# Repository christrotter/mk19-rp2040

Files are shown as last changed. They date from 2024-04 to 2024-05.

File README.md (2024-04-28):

# mk19-rp2040
Attempting to reduce soldering to a minimum - only need to solder the JST-XH headers.  This is the mainboard for the [ArcBoard-mk19](https://github.com/christrotter/qmk_firmware/tree/arcboard-series/keyboards/handwired/arcboard_mk19).

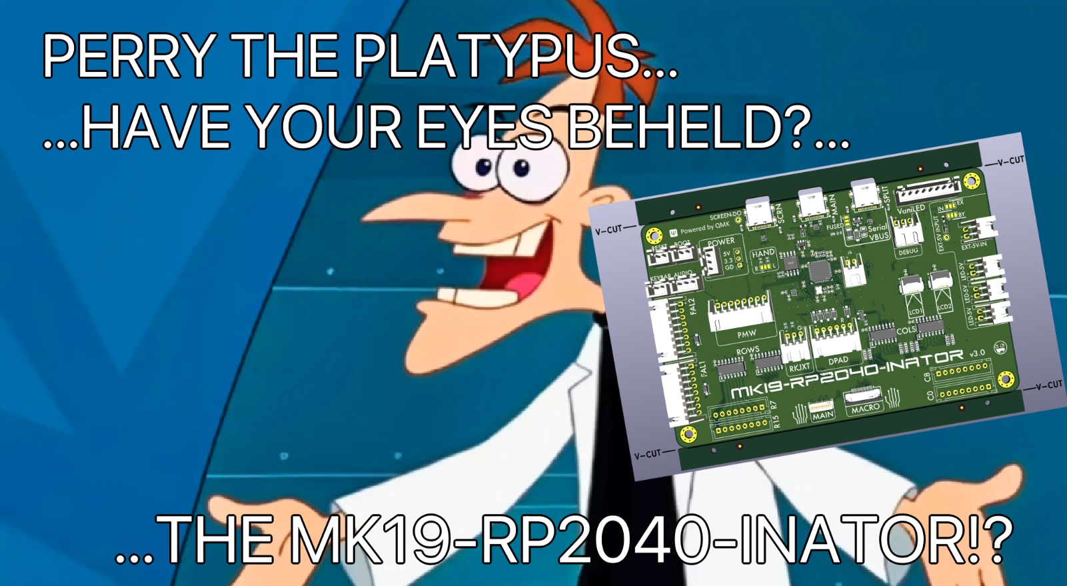
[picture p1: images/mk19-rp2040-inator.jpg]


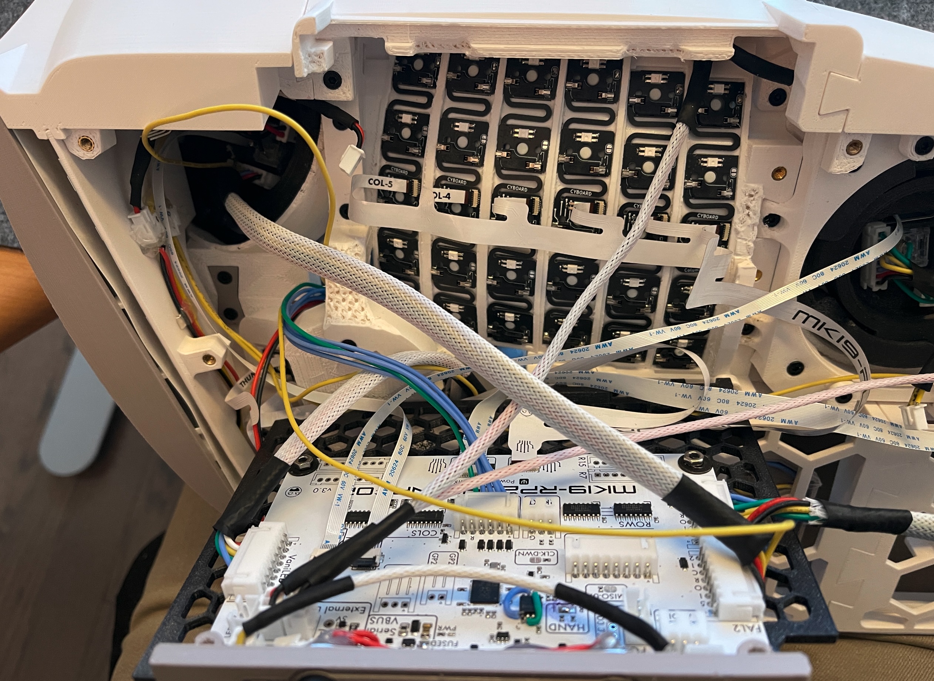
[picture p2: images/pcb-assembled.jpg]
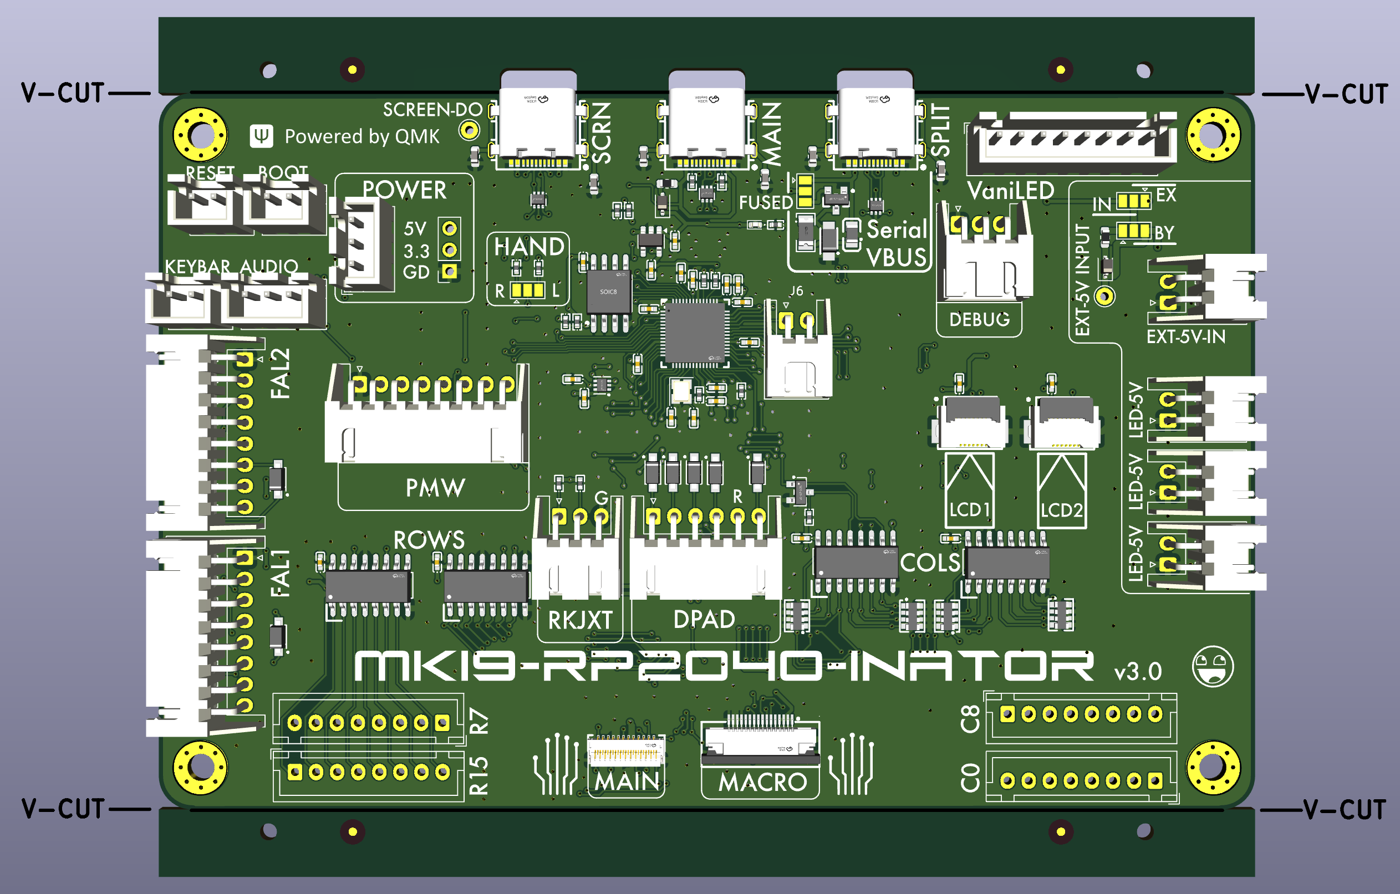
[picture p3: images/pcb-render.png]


# Features
- On-board RP2040 w. 16MB flash (_based on splinktegrated and reference design_)
- USB-C connectivity for main, split, and screen indicators
- Boot and reset button headers
- Serial vbus power protection (_ESD, polyfuse, diode, etc_)
- External 5v input for LED power (_polyfuse, diode_)
- SPI shift registers to handle rows and cols - up to 256 keys per half - with row/col pin breakouts
- SPI LCD outputs via 0.5mm FPC connectors
- 0.3mm FPC connector for [Cyboard](https://www.cyboard.digital/product-page/dactyl-flex-pcbs) connectivity (or via [this](https://github.com/christrotter/mk19-flex-pcb))
- 0.5mm [macropad](https://github.com/christrotter/macropad-pcb) connector
- Dpad input with diodes (_[RKJXT w. encoder](https://github.com/christrotter/rkjxt-mini-breakout), [5-way](https://github.com/christrotter/5way-pcb), or [4-switch dpad](https://github.com/christrotter/microswitch-dpad)_)
- PMW33XX connector
- 2x [Ultrafalcon](https://github.com/christrotter/ultrafalcon) connectors
- VaniLED connector (_GND,5V,4 gpio; for controlling a secondary RP2040 that handles extra LEDs_)
- Audio, debug, spare pin, power breakouts
- Split-handedness pin solder jumper
- Optional SPI clock pull-down and SPI MISO pull-up resistors
- Test points

# Functional notes
- The LED DI/DO chain flows from main keys (_Cyboard_) to the macropad, then to the dpad (_bodged in post-production_), then UF1, UF2, keybar, screen indicators.
- ROW2COL
- Power LED only indicates you have 5v to the board
- Requires QMK's 'matrix lite' custom matrix feature
  - For more info regarding the custom matrix and shift register implementation, see here: https://github.com/christrotter/shift-register-spi-breakout-pcb
- With everything running it sits at around 1500 scan rate
- First flashing requires holding boot while plugging in main USB; subsequent flashes can use double-press reset button or `QK_BOOT`

# Production notes
- Due to putting the v-cuts on the edge cuts layer, all pcb renders are broken.  This is a known bug in JLC's process.  The pre-production verifications render correctly.
- Requires standard assembly which is a big price increase.
- Make sure to have 'production file verification' checked for PCB and PCBA.

## Post-production fixes
- USB lines were backwards
- Two pins (2 & 5) on the flash were reversed
- The v-cuts were on the wrong layer (should be on the edge cuts layer for JLC)

# PCB overview


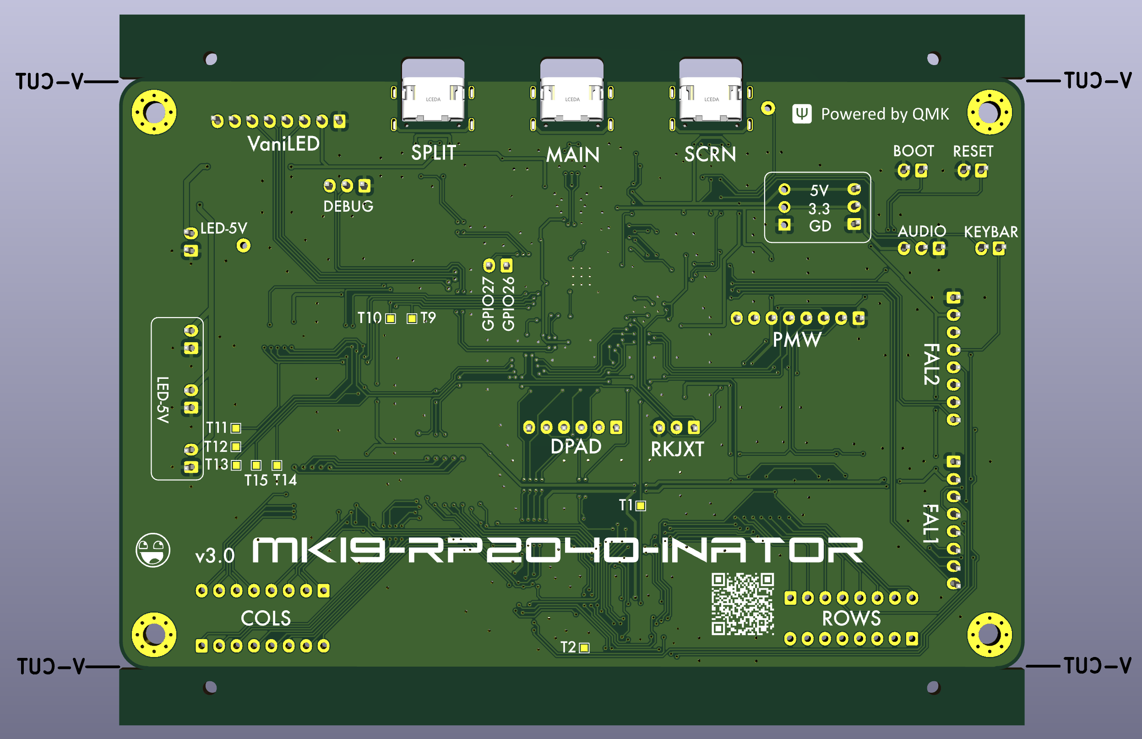
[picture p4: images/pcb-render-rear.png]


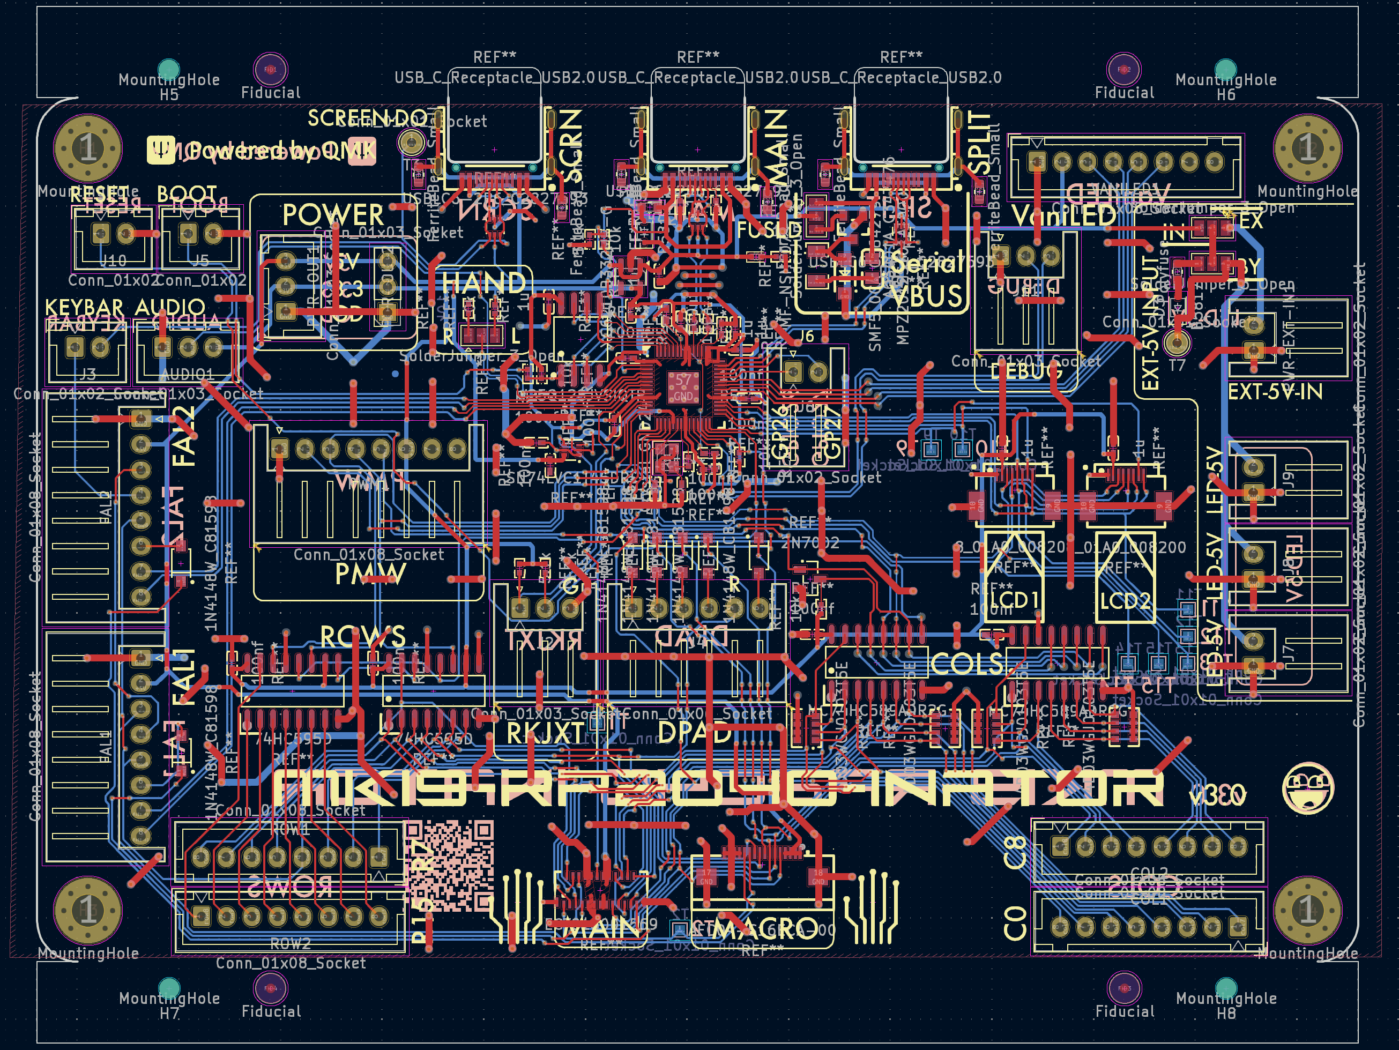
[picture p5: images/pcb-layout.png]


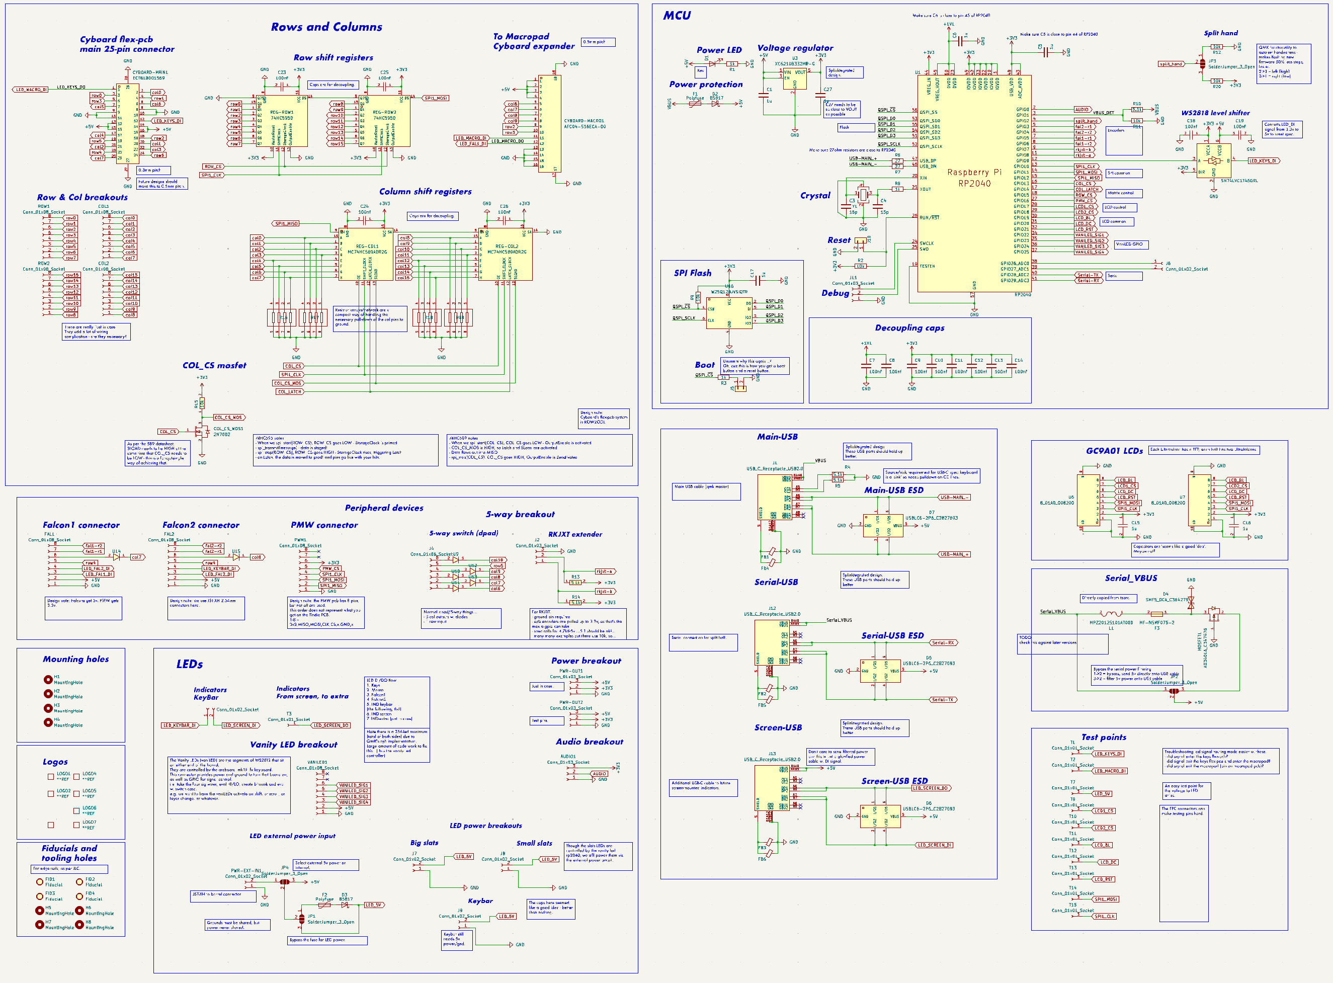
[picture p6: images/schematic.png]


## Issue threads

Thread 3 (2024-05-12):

ESD problems

christrotter, 2024-05-12:
I made the mistake of connecting the shield ground to the logic ground with ferrite beads.  They need to be completely separated.
It could potentially also be the terrible cable bodge due to the usb data +/- mishap, but probably the ferrites.

If/when the board blows up, I'll fix this.

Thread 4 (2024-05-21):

missing dpad leds

christrotter, 2024-05-21:
the dpad leds are rather bodged in, needs to become part of the normal chain.

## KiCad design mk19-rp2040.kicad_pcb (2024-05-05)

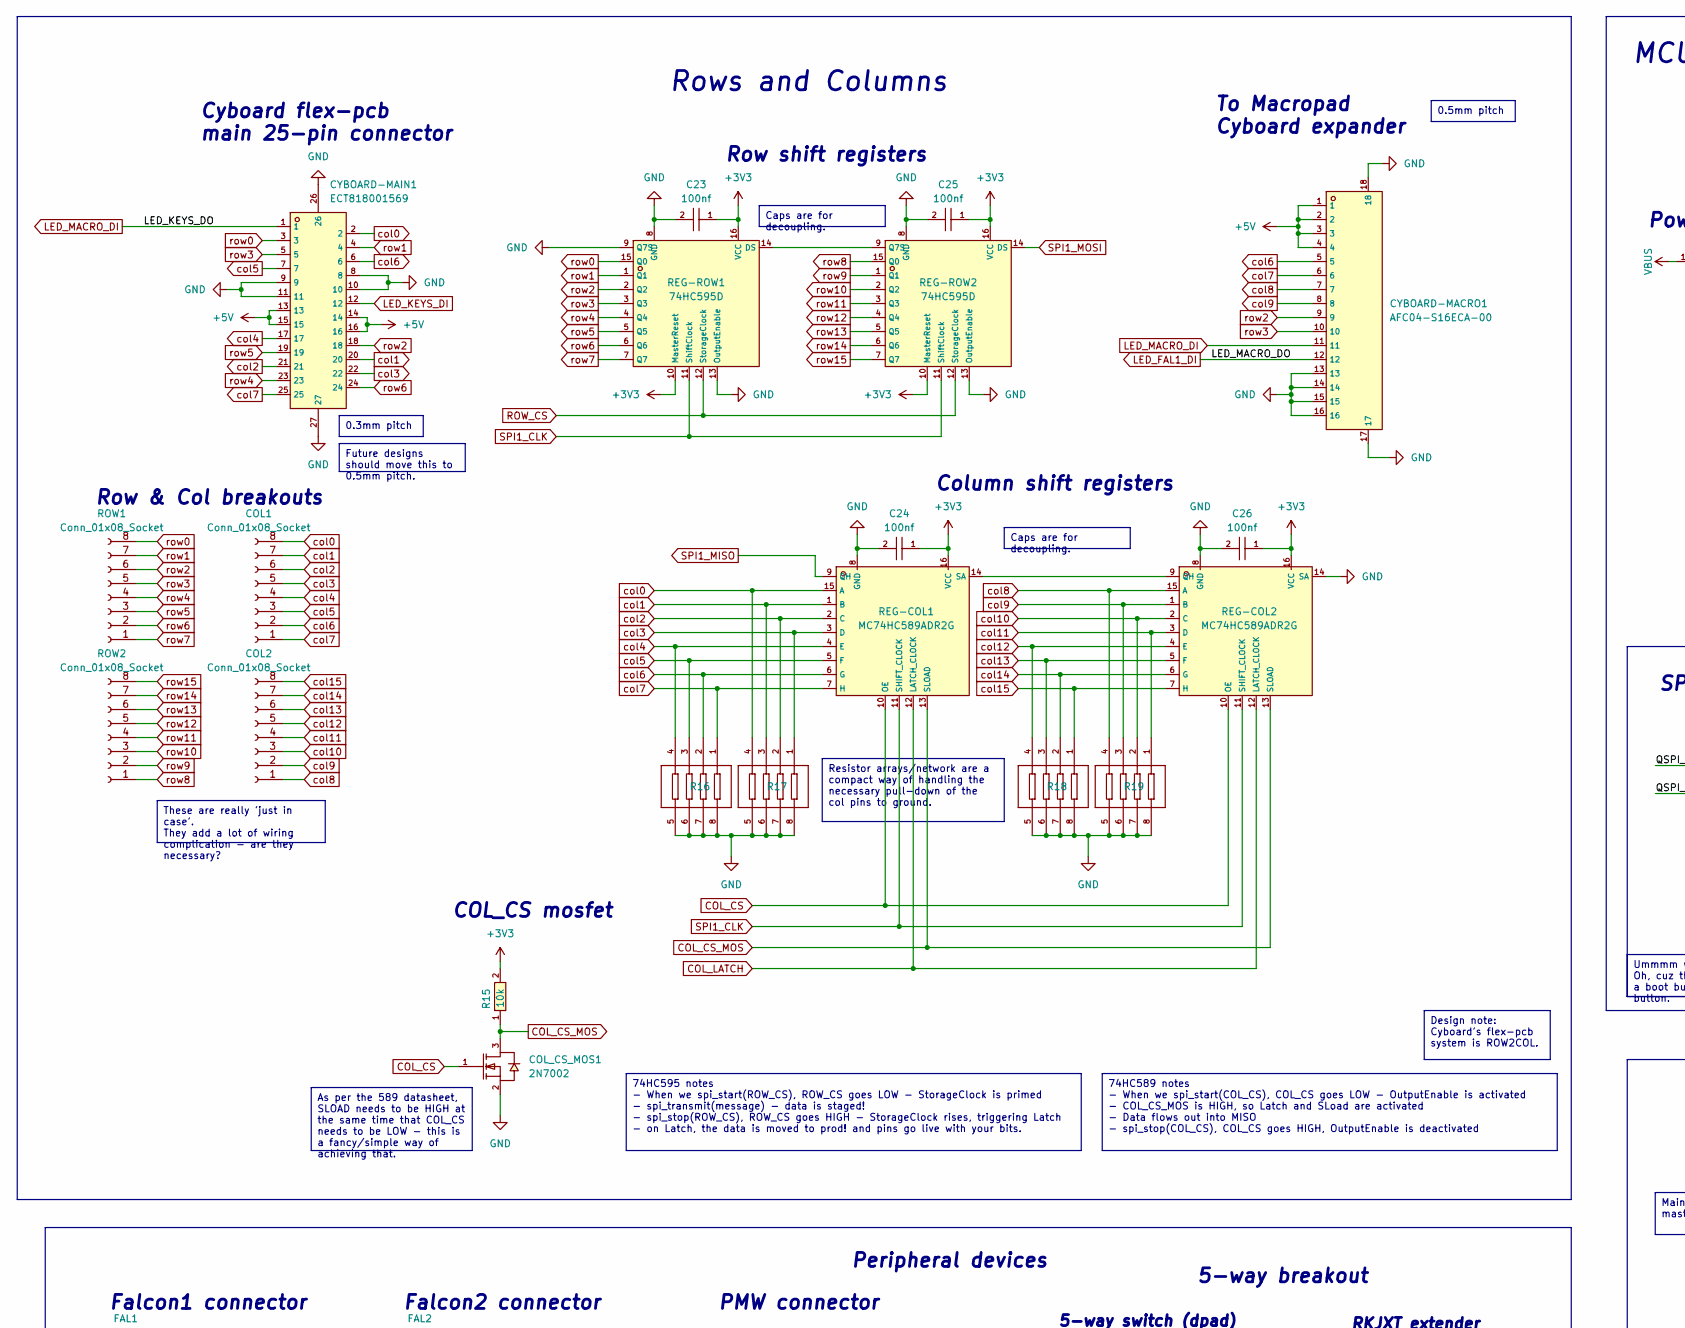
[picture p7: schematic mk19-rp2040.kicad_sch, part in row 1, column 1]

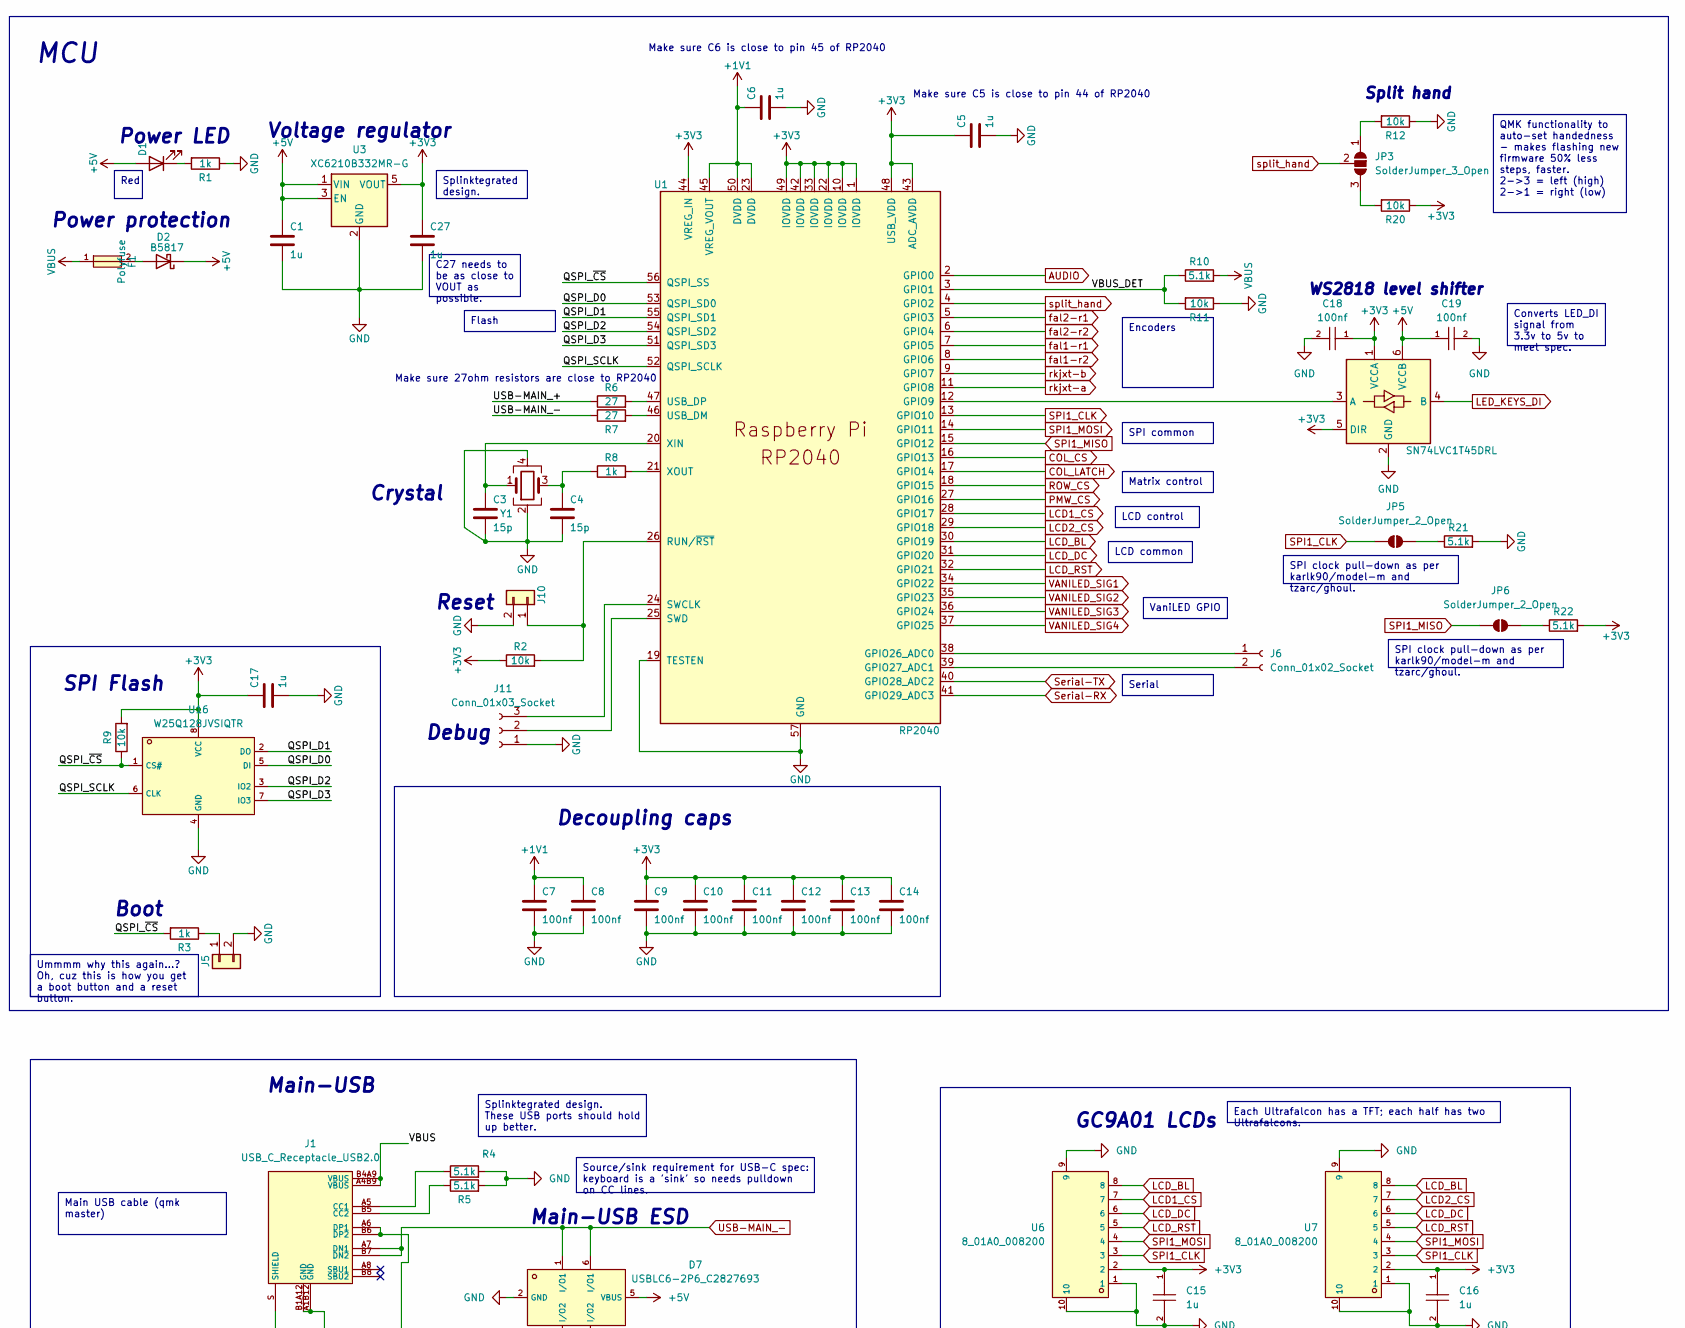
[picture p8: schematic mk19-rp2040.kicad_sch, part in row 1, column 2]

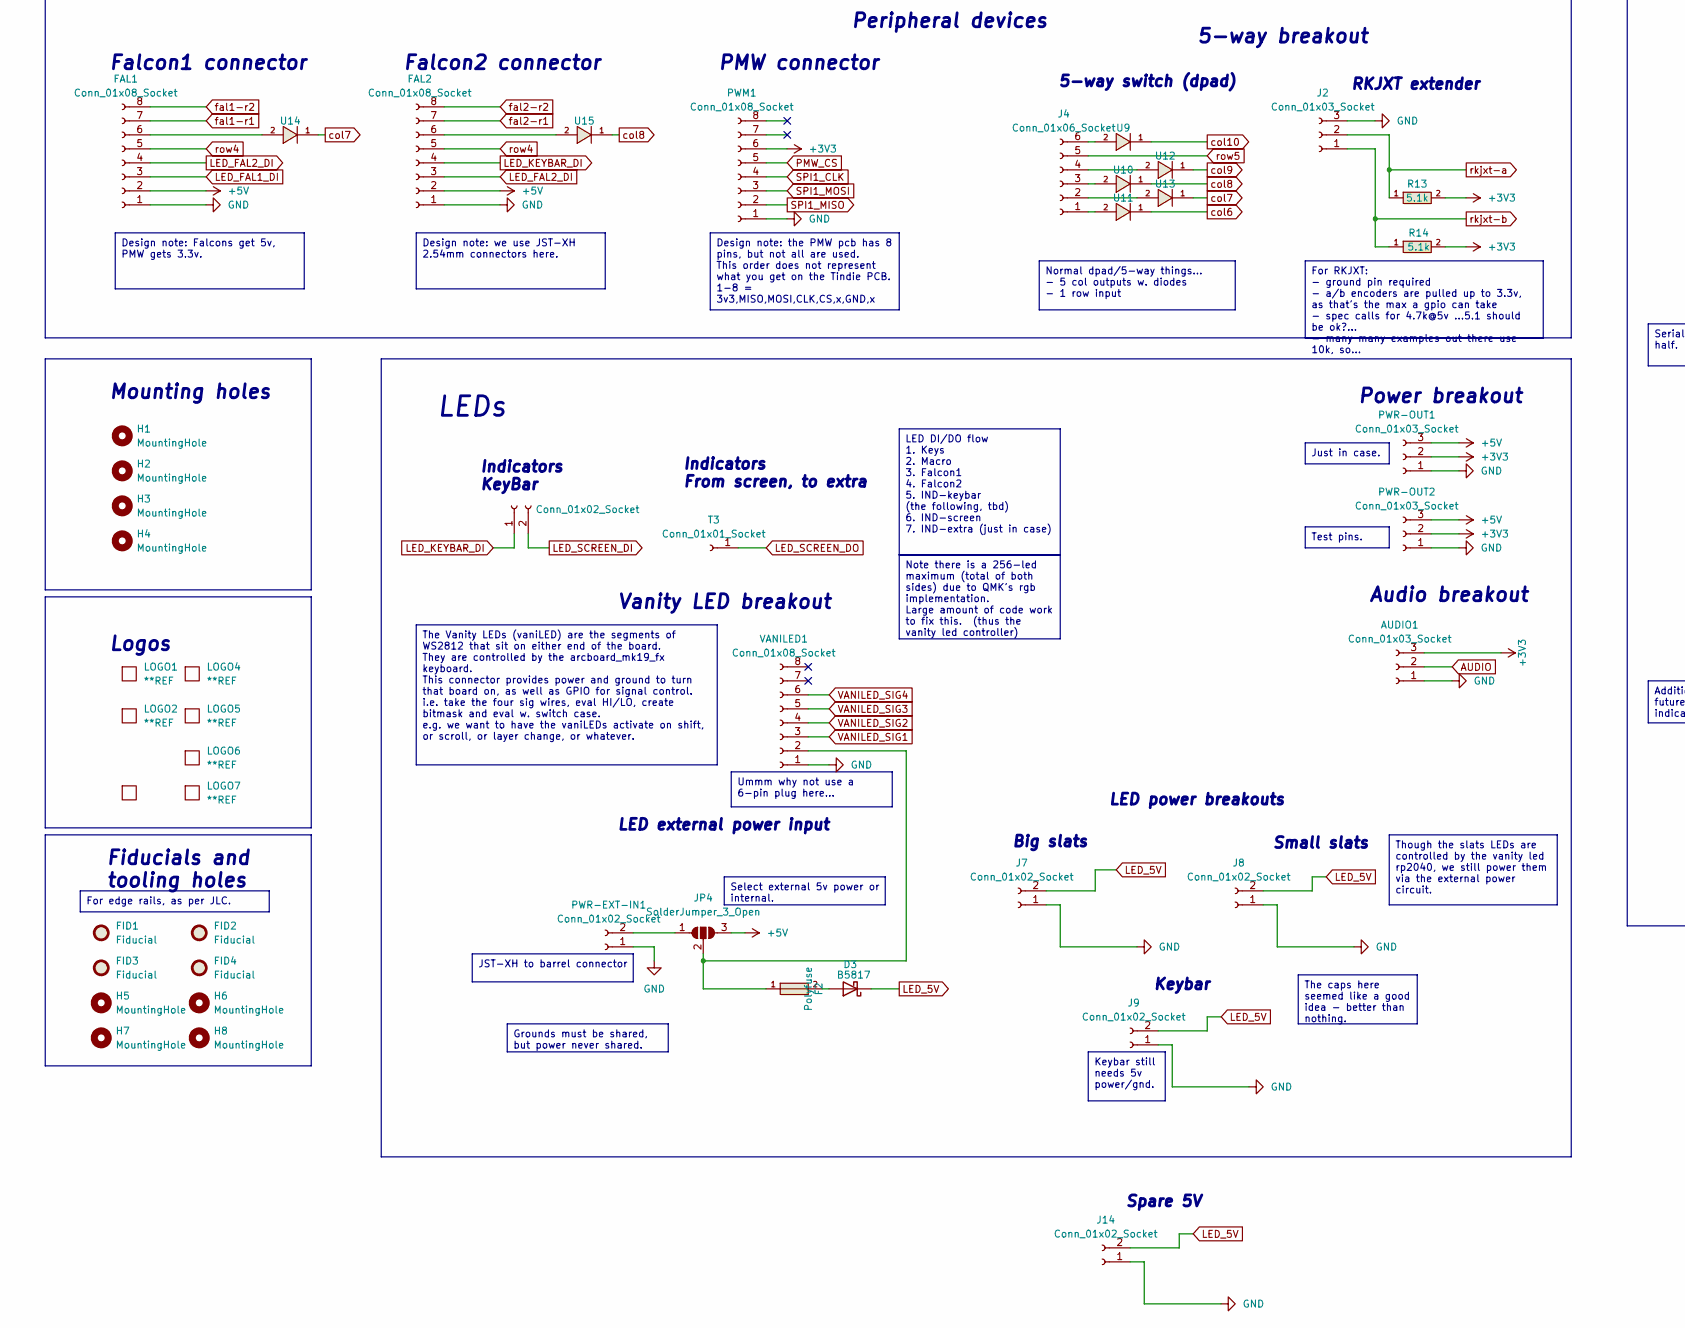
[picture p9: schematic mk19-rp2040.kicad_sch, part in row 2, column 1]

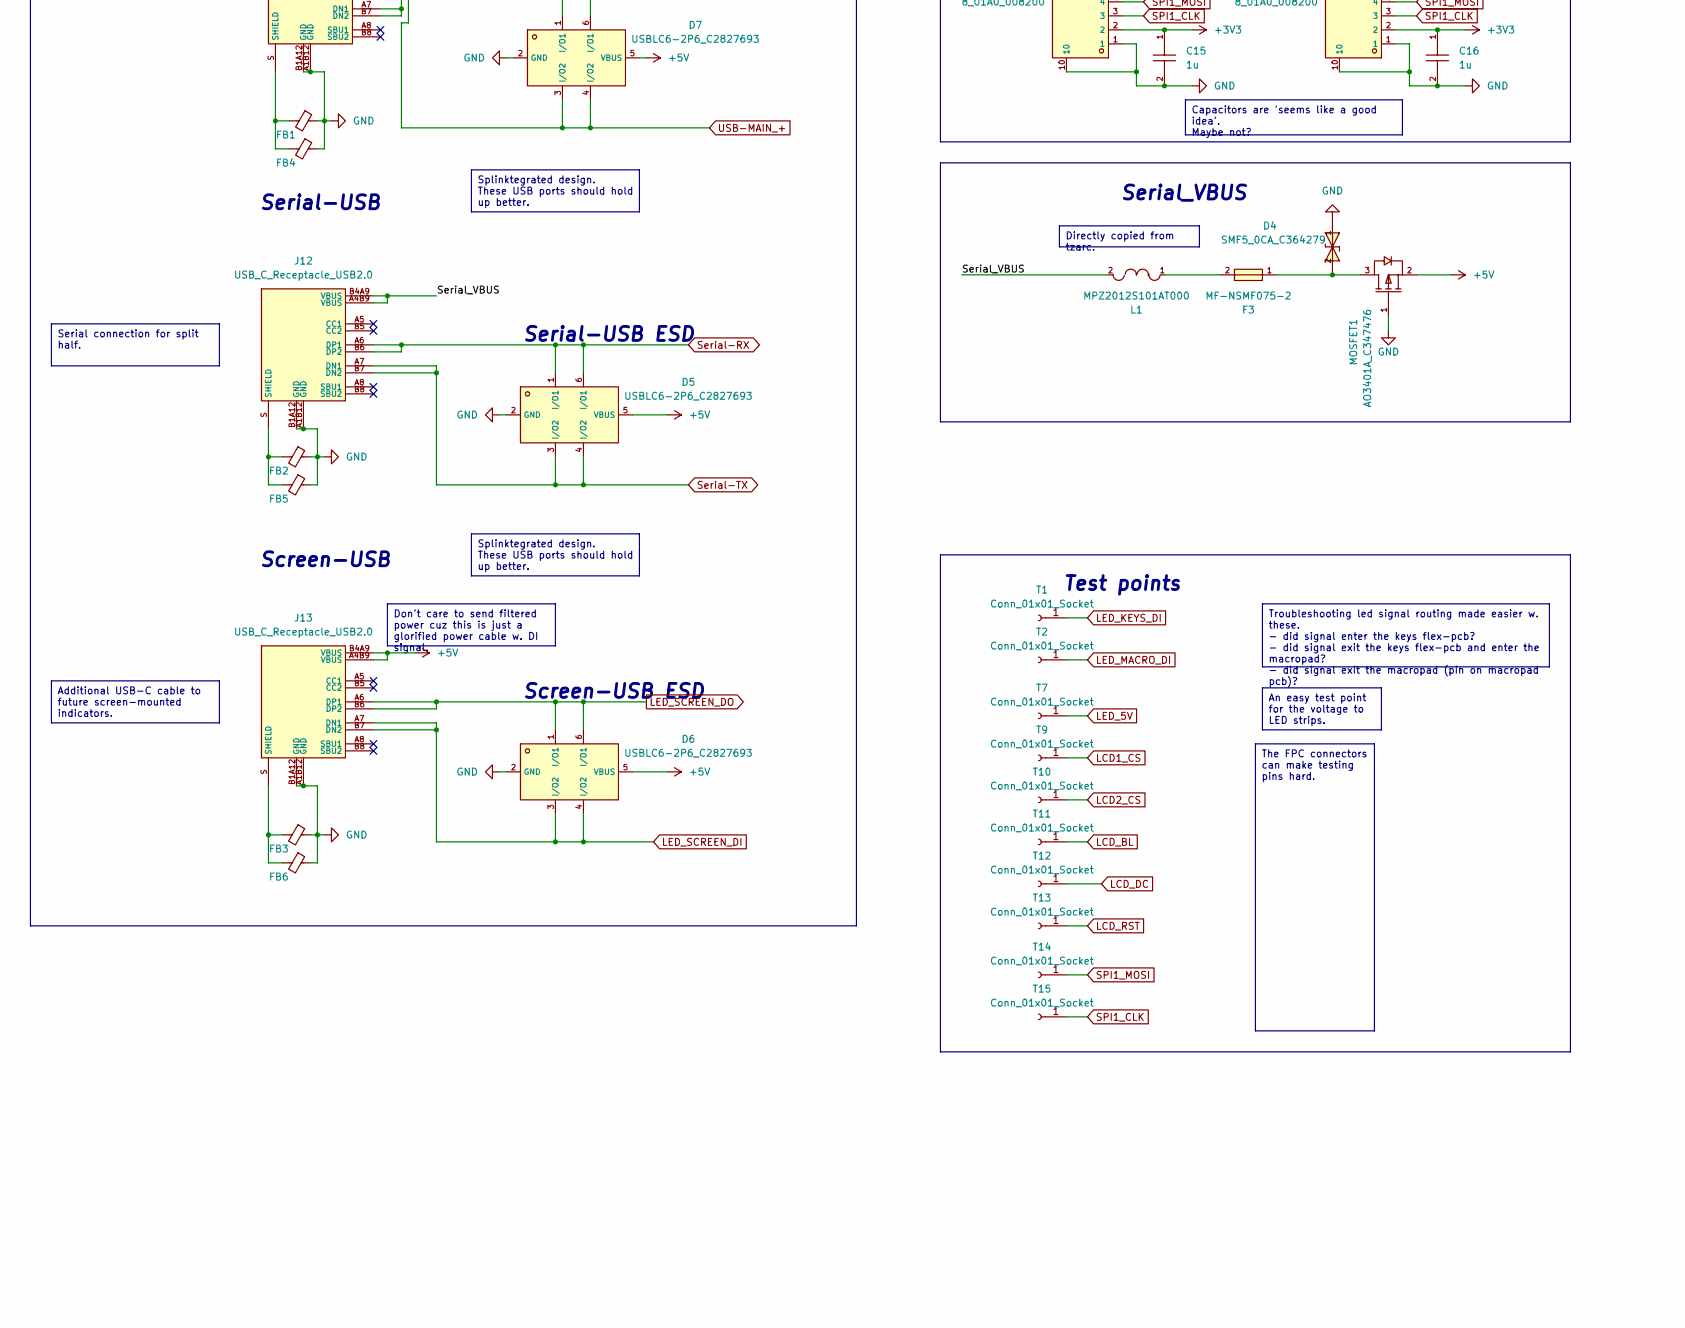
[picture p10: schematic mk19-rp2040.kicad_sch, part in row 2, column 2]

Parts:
AUDIO1: Conn_01x03_Socket; JST_XH_S3B-XH-A_1x03_P2.50mm_Horizontal
C1, C5, C6, C15, C16, C17, C27: 1u; C0402; LCSC C52923
C3, C4: 15p; C0402; LCSC C1548
C7, C8, C9, C10, C11, C12, C13, C14, C18, C19, C23, C24, C25, C26: 100nf; C0402; LCSC C1525
COL1, COL2: Conn_01x08_Socket; JST_XH_B8B-XH-A_1x08_P2.50mm_Vertical
COL_CS_MOS1: 2N7002; SOT-23-3_L2.9-W1.3-P1.90-LS2.4-BR; LCSC C8545
CYBOARD-MACRO1: AFC04-S16ECA-00; FPC-SMD_AFC04-S16ECA-00; LCSC C883640
CYBOARD-MAIN1: ECT818001569; FPC-SMD_ECT818001569; LCSC C711420
D1: LED; LED_0402_1005Metric; LCSC C130719
D2, D3: B5817; D_SOD-323; LCSC C123899
D4: SMF5_0CA_C364279; SOD-123FL_L2.8-W1.8-LS3.7-BI; LCSC C364279
D5, D6, D7: USBLC6-2P6_C2827693; SOT-666-6_L1.6-W1.2-P0.50-LS1.6-BL; LCSC C2827693
F1, F2: Polyfuse; F1206; LCSC C2892425
F3: MF-NSMF075-2; F1206; LCSC C89653
FAL1, FAL2: Conn_01x08_Socket; JST_XH_S8B-XH-A_1x08_P2.50mm_Horizontal
FB1, FB2, FB3, FB4, FB5, FB6: FerriteBead_Small; L_0603_1608Metric; LCSC C98288
FID1, FID2, FID3, FID4: Fiducial; Fiducial_1mm_Mask3mm
H1, H2, H3, H4: MountingHole; MountingHole_3.2mm_M3_Pad_Via
H5, H6, H7, H8: MountingHole; hole-tooling-2mm
J1, J12, J13: USB_C_Receptacle_USB2.0; USB-C-SMD_12P-P0.50-H-F_TYPE-C-31-M-14; LCSC C223907
J2, J11: Conn_01x03_Socket; JST_XH_S3B-XH-A_1x03_P2.50mm_Horizontal
J3, J7, J8, J9, J14: Conn_01x02_Socket; JST_XH_B2B-XH-A_1x02_P2.50mm_Vertical
J4: Conn_01x06_Socket; JST_XH_S6B-XH-A_1x06_P2.50mm_Horizontal
J5, J10: Conn_01x02; JST_XH_B2B-XH-A_1x02_P2.50mm_Vertical
J6: Conn_01x02_Socket; JST_XH_S2B-XH-A_1x02_P2.50mm_Horizontal
JP3, JP4: SolderJumper_3_Open; SolderJumper-3_P1.3mm_Open_Pad1.0x1.5mm
JP5, JP6: SolderJumper_2_Open; SolderJumper-2_P1.3mm_Open_RoundedPad1.0x1.5mm
L1: MPZ2012S101AT000; L0805; LCSC C15957
LED-LVL1: SN74LVC1T45DRL; SOT-563_L1.6-W1.2-P0.50-LS1.6-BR; MPN SN74LVC1T45DRLR; JLC Basic N
LOGO1, LOGO4: **REF; awesome-logo
LOGO2, LOGO5: **REF; qmk-lite
LOGO6, LOGO7: **REF; cyboard-logo-10mm
LOGO8: **REF; qr-mk19-rp2040-10mm
MOSFET1: AO3401A_C347476; SOT-23_L2.9-W1.3-P1.90-LS2.4-BR; LCSC C15127
PWM1: Conn_01x08_Socket; JST_XH_S8B-XH-A_1x08_P2.50mm_Horizontal
PWR-EXT-IN1: Conn_01x02_Socket; JST_XH_S2B-XH-A_1x02_P2.50mm_Horizontal
PWR-OUT1: Conn_01x03_Socket; JST_XH_B3B-XH-A_1x03_P2.50mm_Vertical
PWR-OUT2: Conn_01x03_Socket; PinSocket_1x03_P2.54mm_Vertical
R1, R3, R8: 1k; R0402; LCSC C11702
R2, R9, R11, R12, R15, R20: 10k; R0402; LCSC C25744
R4, R5, R10, R13, R14, R21, R22: 5.1k; R0402; LCSC C25905
R6, R7: 27; R0402; LCSC C25100
R16, R17, R18, R19: 4D03WGJ0103T5E; RES-ARRAY-SMD_0603-8P-L3.2-W1.6-BL; LCSC C29718
REG-COL1, REG-COL2: MC74HC589ADR2G; SOIC-16_L9.9-W3.9-P1.27-LS6.0-BL; LCSC C7343
REG-ROW1, REG-ROW2: 74HC595D; SOIC-16_L9.9-W3.9-P1.27-LS6.0-BL; LCSC C5947
ROW1, ROW2: Conn_01x08_Socket; JST_XH_B8B-XH-A_1x08_P2.50mm_Vertical
T1, T2, T9, T10, T11, T12, T13, T14, T15: Conn_01x01_Socket; TestPoint_Pad_1.0x1.0mm
T3, T7: Conn_01x01_Socket; Pin_D1.0mm_L10.0mm
U1: RP2040; LQFN-56_L7.0-W7.0-P0.4-EP; LCSC C2040
U3: XC6210B332MR-G; SOT-23-5; LCSC C82942
U6, U7: 8_01A0_008200; FPC-SMD_8P-P0.50_8.01A0.008200; LCSC C19188791
U9, U10, U11, U12, U13, U14, U15: 1N4148W_C81598; SOD-123F_L2.7-W1.6-LS3.8-RD; LCSC C81598
U16: W25Q128JVSIQTR; SOIC-8_L5.3-W5.3-P1.27-LS8.0-BL; LCSC C97521
VANILED1: Conn_01x08_Socket; JST_XH_S8B-XH-A_1x08_P2.50mm_Horizontal
Y1: Crystal_GND24; Crystal_SMD_2520-4Pin_2.5x2.0mm; LCSC C2149204

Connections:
+1V1: C6.1, C7.1, C8.1, U1.23 (DVDD), U1.45 (VREG_VOUT), U1.50 (DVDD)
+3V3: AUDIO1.3, C5.1, C9.1, C10.1, C11.1, C12.1, C13.1, C14.1, C15.1, C16.1, C17.1, C18.1, C23.1, C24.1, C25.1, C26.1, C27.1, LED-LVL1.1 (VCCA), LED-LVL1.5 (DIR), PWM1.6, PWR-OUT1.2, PWR-OUT2.2, R2.1, R9.2, R13.2, R14.2, R15.2, R20.1, R22.2, REG-COL1.16 (VCC), REG-COL2.16 (VCC), REG-ROW1.10 (MasterReset), REG-ROW1.16 (VCC), REG-ROW2.10 (MasterReset), REG-ROW2.16 (VCC), U1.1 (IOVDD), U1.10 (IOVDD), U1.22 (IOVDD), U1.33 (IOVDD), U1.42 (IOVDD), U1.43 (ADC_AVDD), U1.44 (VREG_IN), U1.48 (USB_VDD), U1.49 (IOVDD), U3.5 (VOUT), U6.2, U7.2, U16.8 (VCC)
+5V: C1.1, C19.1, CYBOARD-MACRO1.1, CYBOARD-MACRO1.2, CYBOARD-MACRO1.3, CYBOARD-MACRO1.4, CYBOARD-MAIN1.13, CYBOARD-MAIN1.14, CYBOARD-MAIN1.15, CYBOARD-MAIN1.16, D1.2 (A), D2.1 (K), D5.5 (VBUS), D6.5 (VBUS), D7.5 (VBUS), FAL1.2, FAL2.2, J13.A4B9 (VBUS), J13.B4A9 (VBUS), JP4.3 (B), LED-LVL1.6 (VCCB), MOSFET1.2 (S), PWR-OUT1.3, PWR-OUT2.3, U3.1 (VIN), U3.3 (EN)
/QSPI_D0: U1.53 (QSPI_SD0), U16.5 (DI)
/QSPI_D1: U1.55 (QSPI_SD1), U16.2 (DO)
/QSPI_D2: U1.54 (QSPI_SD2), U16.3 (IO2)
/QSPI_D3: U1.51 (QSPI_SD3), U16.7 (IO3)
/QSPI_SCLK: U1.52 (QSPI_SCLK), U16.6 (CLK)
/QSPI_~CS: R3.2, R9.1, U1.56 (QSPI_SS), U16.1 (CS#)
/Serial_VBUS: J12.A4B9 (VBUS), J12.B4A9 (VBUS), L1.2
/VBUS_DET: R10.1, R11.2, U1.3 (GPIO1)
AUDIO: AUDIO1.2, U1.2 (GPIO0)
COL_CS: COL_CS_MOS1.1 (G), REG-COL1.10 (OE), REG-COL2.10 (OE), U1.16 (GPIO13)
COL_CS_MOS: COL_CS_MOS1.3 (D), R15.1, REG-COL1.13 (SLOAD), REG-COL2.13 (SLOAD)
COL_LATCH: REG-COL1.12 (LATCH_CLOCK), REG-COL2.12 (LATCH_CLOCK), U1.17 (GPIO14)
GND: AUDIO1.1, C1.2, C3.2, C4.2, C5.2, C6.2, C7.2, C8.2, C9.2, C10.2, C11.2, C12.2, C13.2, C14.2, C15.2, C16.2, C17.2, C18.2, C19.2, C23.2, C24.2, C25.2, C26.2, C27.2, COL_CS_MOS1.2 (S), CYBOARD-MACRO1.13, CYBOARD-MACRO1.14, CYBOARD-MACRO1.15, CYBOARD-MACRO1.16, CYBOARD-MACRO1.17, CYBOARD-MACRO1.18, CYBOARD-MAIN1.8, CYBOARD-MAIN1.9, CYBOARD-MAIN1.10, CYBOARD-MAIN1.11, CYBOARD-MAIN1.26, CYBOARD-MAIN1.27, D4.1 (K), D5.2 (GND), D6.2 (GND), D7.2 (GND), FAL1.1, FAL2.1, FB1.1, FB2.1, FB3.1, FB4.1, FB5.1, FB6.1, J1.A1B12 (GND), J1.B1A12 (GND), J2.3, J5.2, J7.1, J8.1, J9.1, J10.2, J11.1, J12.A1B12 (GND), J12.B1A12 (GND), J13.A1B12 (GND), J13.B1A12 (GND), J14.1, LED-LVL1.2 (GND), MOSFET1.1 (G), PWM1.1, PWR-EXT-IN1.1, PWR-OUT1.1, PWR-OUT2.1, R1.1, R4.2, R5.2, R11.1, R12.1, R16.5, R16.6, R16.7, R16.8, R17.5, R17.6, R17.7, R17.8, R18.5, R18.6, R18.7, R18.8, R19.5, R19.6, R19.7, R19.8, R21.2, REG-COL1.8 (GND), REG-COL2.8 (GND), REG-COL2.14 (SA), REG-ROW1.8 (GND), REG-ROW1.9 (Q7S), REG-ROW1.13 (OutputEnable), REG-ROW2.8 (GND), REG-ROW2.13 (OutputEnable), U1.19 (TESTEN), U1.57 (GND), U3.2 (GND), U6.1, U6.9, U6.10, U7.1, U7.9, U7.10, U16.4 (GND), VANILED1.1, Y1.2, Y1.4
LCD1_CS: T9.1, U1.28 (GPIO17), U6.7
LCD2_CS: T10.1, U1.29 (GPIO18), U7.7
LCD_BL: T11.1, U1.30 (GPIO19), U6.8, U7.8
LCD_DC: T12.1, U1.31 (GPIO20), U6.6, U7.6
LCD_RST: T13.1, U1.32 (GPIO21), U6.5, U7.5
LED_5V: D3.1 (K), J7.2, J8.2, J9.2, J14.2, T7.1
LED_FAL1_DI: CYBOARD-MACRO1.12, FAL1.3
LED_FAL2_DI: FAL1.4, FAL2.3
LED_KEYBAR_DI: FAL2.4, J3.1
LED_KEYS_DI: CYBOARD-MAIN1.12, LED-LVL1.4 (B), T1.1
LED_MACRO_DI: CYBOARD-MACRO1.11, CYBOARD-MAIN1.1, T2.1
LED_SCREEN_DI: D6.3 (I/O2), D6.4 (I/O2), J3.2, J13.A7 (DN1), J13.B7 (DN2)
LED_SCREEN_DO: D6.1 (I/O1), D6.6 (I/O1), J13.A6 (DP1), J13.B6 (DP2), T3.1
unnamed: C4.1, R8.1, Y1.3
unnamed: D1.1 (K), R1.2
unnamed: D2.2 (A), F1.2
unnamed: D3.2 (A), F2.2
unnamed: D4.2 (A), F3.1, MOSFET1.3 (D)
unnamed: F3.2, L1.1
unnamed: FAL1.6, U14.2 (A)
unnamed: FAL2.6, U15.2 (A)
unnamed: J1.A5 (CC1), R4.1
unnamed: J1.B5 (CC2), R5.1
unnamed: FB1.2, FB4.2, J1.S (SHIELD)
unnamed: J4.1, U11.2 (A)
unnamed: J4.2, U13.2 (A)
unnamed: J4.3, U10.2 (A)
unnamed: J4.4, U12.2 (A)
unnamed: J4.6, U9.2 (A)
unnamed: J5.1, R3.1
unnamed: J6.1, U1.38 (GPIO26_ADC0)
unnamed: J6.2, U1.39 (GPIO27_ADC1)
unnamed: J10.1, R2.2, U1.26 (RUN/~RST)
unnamed: J11.2, U1.25 (SWD)
unnamed: J11.3, U1.24 (SWCLK)
unnamed: FB2.2, FB5.2, J12.S (SHIELD)
unnamed: FB3.2, FB6.2, J13.S (SHIELD)
unnamed: JP3.1 (A), R12.2
unnamed: JP3.3 (B), R20.2
unnamed: JP4.1 (A), PWR-EXT-IN1.2
unnamed: F2.1, JP4.2 (C), VANILED1.2
unnamed: JP5.2 (B), R21.1
unnamed: JP6.2 (B), R22.1
unnamed: LED-LVL1.3 (A), U1.12 (GPIO9)
unnamed: REG-COL1.14 (SA), REG-COL2.9 (QH)
unnamed: REG-ROW1.14 (DS), REG-ROW2.9 (Q7S)
unnamed: R7.2, U1.46 (USB_DM)
unnamed: R6.2, U1.47 (USB_DP)
unnamed: C3.1, U1.20 (XIN), Y1.1
unnamed: R8.2, U1.21 (XOUT)
PMW_CS: PWM1.5, U1.27 (GPIO16)
ROW_CS: REG-ROW1.12 (StorageClock), REG-ROW2.12 (StorageClock), U1.18 (GPIO15)
SPI1_CLK: JP5.1 (A), PWM1.4, REG-COL1.11 (SHIFT_CLOCK), REG-COL2.11 (SHIFT_CLOCK), REG-ROW1.11 (ShiftClock), REG-ROW2.11 (ShiftClock), T15.1, U1.13 (GPIO10), U6.3, U7.3
SPI1_MISO: JP6.1 (A), PWM1.2, REG-COL1.9 (QH), U1.15 (GPIO12)
SPI1_MOSI: PWM1.3, REG-ROW2.14 (DS), T14.1, U1.14 (GPIO11), U6.4, U7.4
Serial-RX: D5.1 (I/O1), D5.6 (I/O1), J12.A6 (DP1), J12.B6 (DP2), U1.41 (GPIO29_ADC3)
Serial-TX: D5.3 (I/O2), D5.4 (I/O2), J12.A7 (DN1), J12.B7 (DN2), U1.40 (GPIO28_ADC2)
USB-MAIN_+: D7.3 (I/O2), D7.4 (I/O2), J1.A6 (DP1), J1.B6 (DP2), R6.1
USB-MAIN_-: D7.1 (I/O1), D7.6 (I/O1), J1.A7 (DN1), J1.B7 (DN2), R7.1
VANILED_SIG1: U1.34 (GPIO22), VANILED1.3
VANILED_SIG2: U1.35 (GPIO23), VANILED1.4
VANILED_SIG3: U1.36 (GPIO24), VANILED1.5
VANILED_SIG4: U1.37 (GPIO25), VANILED1.6
VBUS: F1.1, J1.A4B9 (VBUS), J1.B4A9 (VBUS), R10.2
col0: COL1.8, CYBOARD-MAIN1.2, R17.4, REG-COL1.15 (A)
col1: COL1.7, CYBOARD-MAIN1.20, R17.3, REG-COL1.1 (B)
col2: COL1.6, CYBOARD-MAIN1.21, R17.2, REG-COL1.2 (C)
col3: COL1.5, CYBOARD-MAIN1.22, R17.1, REG-COL1.3 (D)
col4: COL1.4, CYBOARD-MAIN1.17, R16.4, REG-COL1.4 (E)
col5: COL1.3, CYBOARD-MAIN1.7, R16.3, REG-COL1.5 (F)
col6: COL1.2, CYBOARD-MACRO1.5, CYBOARD-MAIN1.6, R16.2, REG-COL1.6 (G), U11.1 (K)
col7: COL1.1, CYBOARD-MACRO1.6, CYBOARD-MAIN1.25, R16.1, REG-COL1.7 (H), U13.1 (K), U14.1 (K)
col8: COL2.1, CYBOARD-MACRO1.7, R19.4, REG-COL2.15 (A), U10.1 (K), U15.1 (K)
col9: COL2.2, CYBOARD-MACRO1.8, R19.3, REG-COL2.1 (B), U12.1 (K)
col10: COL2.3, R19.2, REG-COL2.2 (C), U9.1 (K)
col11: COL2.4, R19.1, REG-COL2.3 (D)
col12: COL2.5, R18.4, REG-COL2.4 (E)
col13: COL2.6, R18.3, REG-COL2.5 (F)
col14: COL2.7, R18.2, REG-COL2.6 (G)
col15: COL2.8, R18.1, REG-COL2.7 (H)
fal1-r1: FAL1.7, U1.7 (GPIO5)
fal1-r2: FAL1.8, U1.8 (GPIO6)
fal2-r1: FAL2.7, U1.5 (GPIO3)
fal2-r2: FAL2.8, U1.6 (GPIO4)
rkjxt-a: J2.2, R13.1, U1.11 (GPIO8)
rkjxt-b: J2.1, R14.1, U1.9 (GPIO7)
row0: CYBOARD-MAIN1.3, REG-ROW1.15 (Q0), ROW1.8
row1: CYBOARD-MAIN1.4, REG-ROW1.1 (Q1), ROW1.7
row2: CYBOARD-MACRO1.9, CYBOARD-MAIN1.18, REG-ROW1.2 (Q2), ROW1.6
row3: CYBOARD-MACRO1.10, CYBOARD-MAIN1.5, REG-ROW1.3 (Q3), ROW1.5
row4: CYBOARD-MAIN1.23, FAL1.5, FAL2.5, REG-ROW1.4 (Q4), ROW1.4
row5: CYBOARD-MAIN1.19, J4.5, REG-ROW1.5 (Q5), ROW1.3
row6: CYBOARD-MAIN1.24, REG-ROW1.6 (Q6), ROW1.2
row7: REG-ROW1.7 (Q7), ROW1.1
row8: REG-ROW2.15 (Q0), ROW2.1
row9: REG-ROW2.1 (Q1), ROW2.2
row10: REG-ROW2.2 (Q2), ROW2.3
row11: REG-ROW2.3 (Q3), ROW2.4
row12: REG-ROW2.4 (Q4), ROW2.5
row13: REG-ROW2.5 (Q5), ROW2.6
row14: REG-ROW2.6 (Q6), ROW2.7
row15: REG-ROW2.7 (Q7), ROW2.8
split_hand: JP3.2 (C), U1.4 (GPIO2)

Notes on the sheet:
74HC589 notes - When we spi_start(COL_CS), COL_CS goes LOW - OutputEnable is activated - COL_CS_MOS is HIGH, so Latch and SLoad are activated - Data flows out into MISO - spi_stop(COL_CS), COL_CS goes HIGH, OutputEnable is deactivated
SPI clock pull-down as per karlk90/model-m and tzarc/ghoul.
LED DI/DO flow 1. Keys 2. Macro 3. Falcon1 4. Falcon2 5. IND-keybar (the following, tbd) 6. IND-screen 7. IND-extra (just in case)
Grounds must be shared, but power never shared.
For RKJXT: - ground pin required - a/b encoders are pulled up to 3.3v, as that's the max a gpio can take - spec calls for 4.7k@5v ...5.1 should be ok?... - many many examples out there use 10k, so...
The Vanity LEDs (vaniLED) are the segments of WS2812 that sit on either end of the board. They are controlled by the arcboard_mk19_fx keyboard. This connector provides power and ground to turn that board on, as well as GPIO for signal control. i.e. take the four sig wires, eval HI/LO, create bitmas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
Caps are for decoupling.
0.5mm pitch
0.3mm pitch
The caps here seemed like a good idea - better than nothing.
Design note: Falcons get 5v, PMW gets 3.3v.
LCD control
Main USB cable (qmk master)
Resistor arrays/network are a compact way of handling the necessary pull-down of the col pins to ground.
Select external 5v power or internal.
Keybar still needs 5v power/gnd.
As per the 589 datasheet, SLOAD needs to be HIGH at the same time that COL_CS needs to be LOW - this is a fancy/simple way of achieving that.
Matrix control
Each Ultrafalcon has a TFT; each half has two Ultrafalcons.
Splinktegrated design.
An easy test point for the voltage to LED strips.
Additional USB-C cable to future screen-mounted indicators.
QMK functionality to auto-set handedness - makes flashing new firmware 50% less steps, faster. 2->3 = left (high) 2->1 = right (low)
Don't care to send filtered power cuz this is just a glorified power cable w. DI signal.
Source/sink requirement for USB-C spec: keyboard is a 'sink' so needs pulldown on CC lines.
Future designs should move this to 0.5mm pitch.
These are really 'just in case'. They add a lot of wiring complication - are they necessary?
JST-XH to barrel connector
Splinktegrated design. These USB ports should hold up better.
Design note: the PMW pcb has 8 pins, but not all are used. This order does not represent what you get on the Tindie PCB. 1-8 = 3v3,MISO,MOSI,CLK,CS,x,GND,x
Capacitors are 'seems like a good idea'. Maybe not?
Ummm why not use a 6-pin plug here...
74HC595 notes - When we spi_start(ROW_CS), ROW_CS goes LOW - StorageClock is primed - spi_transmit(message) - data is staged! - spi_stop(ROW_CS), ROW_CS goes HIGH - StorageClock rises, triggering Latch - on Latch, the data is moved to prod! and pins go live with your bits.
Though the slats LEDs are controlled by the vanity led rp2040, we still power them via the external power circuit.
VaniLED GPIO
SPI common
Design note: we use JST-XH 2.54mm connectors here.
Directly copied from tzarc.
Encoders
Red

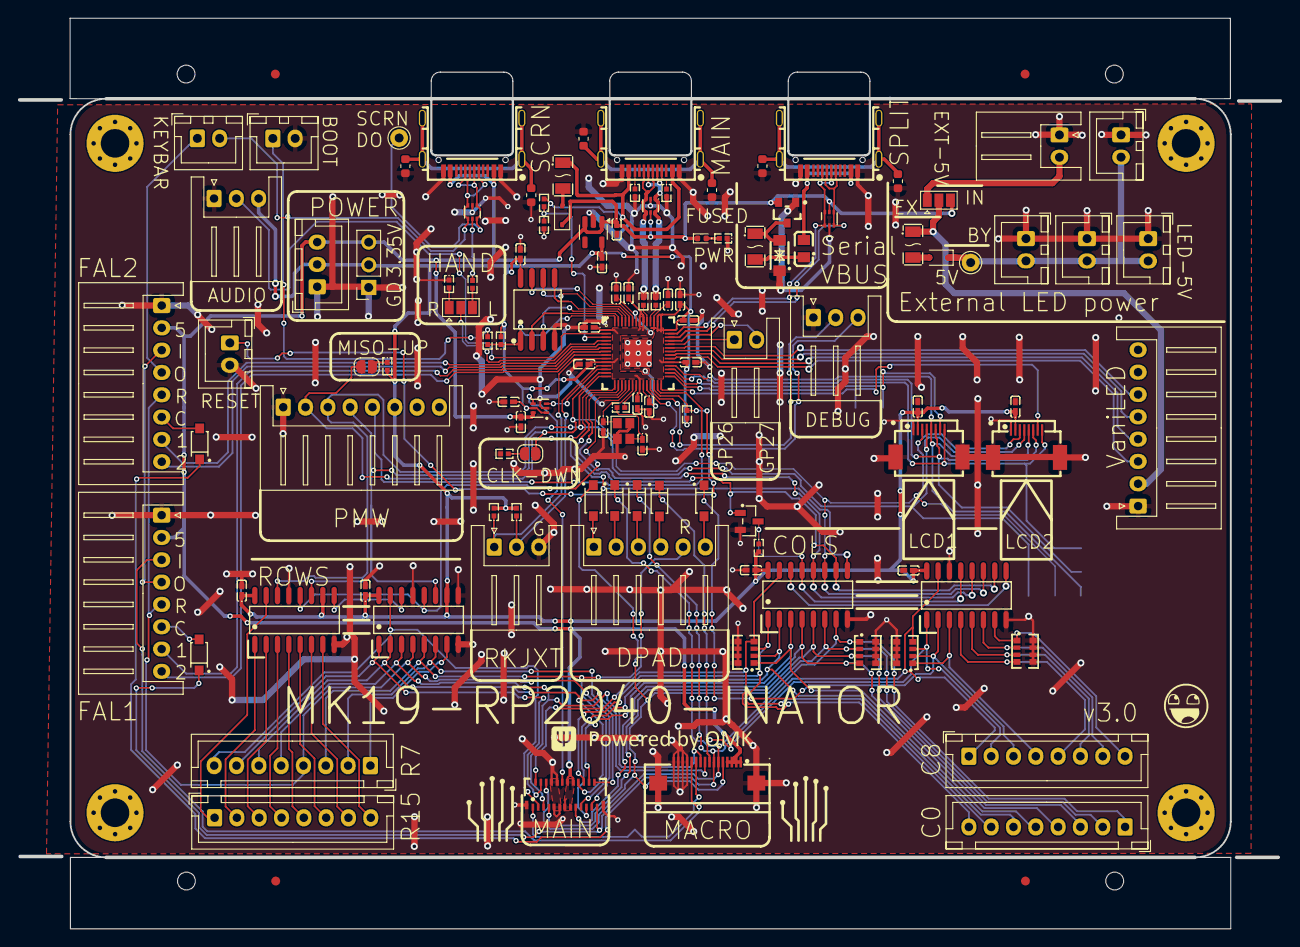
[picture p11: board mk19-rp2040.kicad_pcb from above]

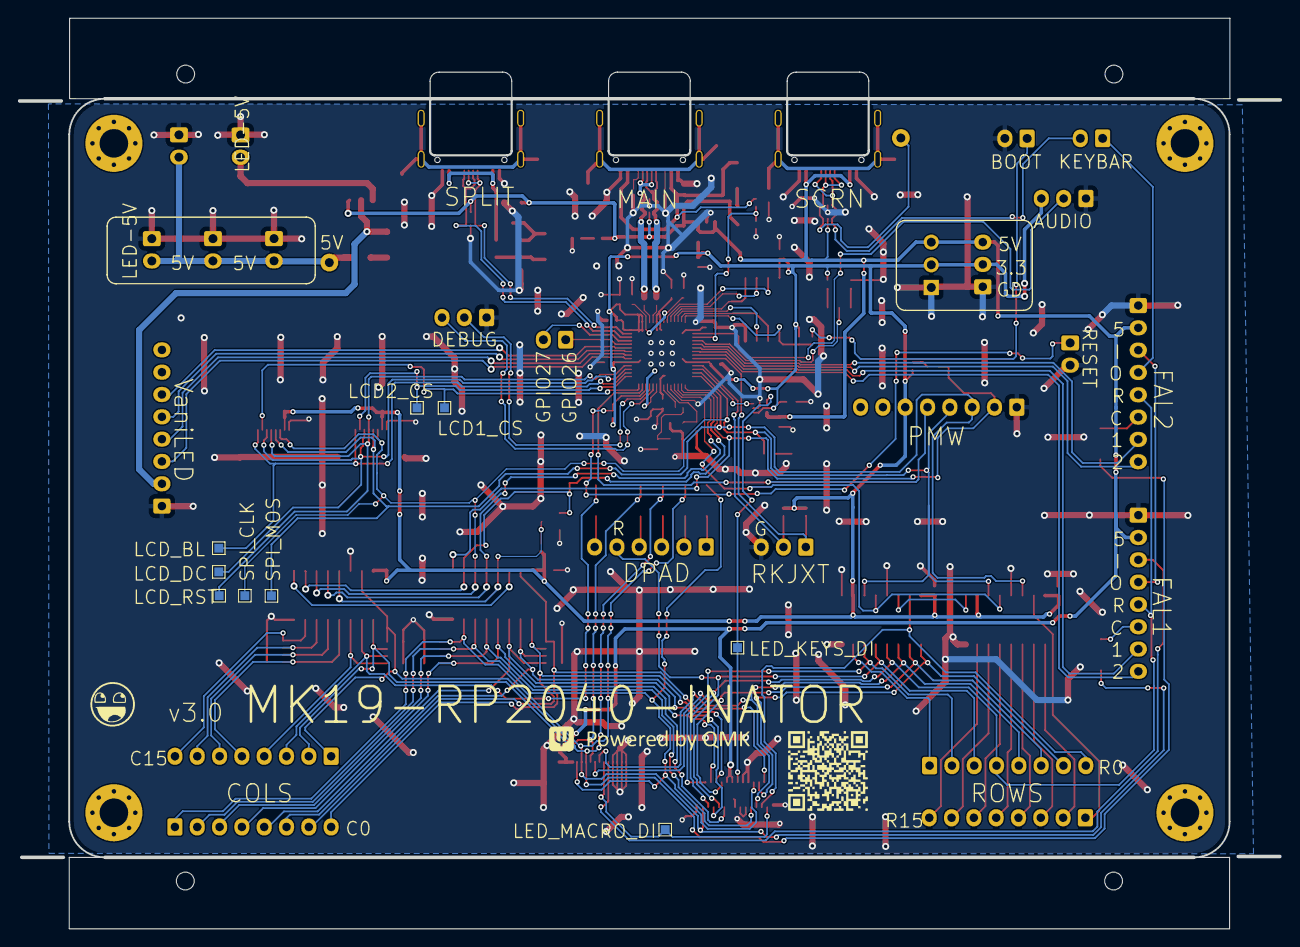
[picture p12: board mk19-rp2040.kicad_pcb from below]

Board: 2 copper layers, 141.2 x 102.0 mm, 144 parts (12 on the bottom side), 119 nets.

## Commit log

2024-03-12 starting work, base schematic created
    [mk19-rp2040.kicad_pcb, mk19-rp2040.kicad_sch]
2024-03-13 starting on first pass at placing components
    [mk19-rp2040.kicad_pcb, mk19-rp2040.kicad_sch]
2024-03-19 added handedness, led signal breakout, more
    [mk19-rp2040.kicad_sch]
2024-03-19 fixed led situation, added diodes, fixed eh-xh confusion, more
    [mk19-rp2040.kicad_sch]
2024-03-20 more fixes, including rkjxt
    [mk19-rp2040.kicad_sch]
2024-03-20 adding a lot of notes, fixes
    [mk19-rp2040.kicad_sch]
2024-03-20 minor formatting
    [mk19-rp2040.kicad_sch]
2024-03-20 some bad footprints, other fixes
    [mk19-rp2040.kicad_pcb, mk19-rp2040.kicad_sch]
2024-03-20 progress update
    [mk19-rp2040.kicad_pcb, mk19-rp2040.kicad_sch]
2024-03-21 getting close to having the rp2040 traced
    [mk19-rp2040.kicad_pcb, mk19-rp2040.kicad_sch]
2024-03-22 more progress
    [mk19-rp2040.kicad_pcb, mk19-rp2040.kicad_sch]
2024-03-22 even more progress, starting to come together.
    [mk19-rp2040.kicad_pcb, mk19-rp2040.kicad_sch]
2024-03-23 almost done
    [mk19-rp2040.kicad_pcb, mk19-rp2040.kicad_sch]
2024-03-23 drc passing, everything hooked up
    [mk19-rp2040.kicad_pcb, mk19-rp2040.kicad_sch]
2024-03-23 more changes, pcba insights coming next
    [mk19-rp2040.kicad_pcb, mk19-rp2040.kicad_sch]
2024-03-24 reworking some of this, copy paste introduced errors whee
    [mk19-rp2040.kicad_pcb, mk19-rp2040.kicad_sch]
2024-03-25 drc passing, bom generating correctly, silkscreen v1
    [mk19-rp2040.kicad_pcb, mk19-rp2040.kicad_sch]
2024-03-25 getting manufacturing bits ready
    [mk19-rp2040.kicad_pcb, mk19-rp2040.kicad_sch]
2024-03-25 moving away from through-hole test points
    [mk19-rp2040.kicad_pcb, mk19-rp2040.kicad_sch]
2024-03-25 relocating boot debug reset to edges of board, edge rail improvements
    [mk19-rp2040.kicad_pcb, mk19-rp2040.kicad_sch]
2024-03-27 just about ready to produce
    [mk19-rp2040.kicad_pcb, mk19-rp2040.kicad_sch]
2024-03-27 minor fix
    [mk19-rp2040.kicad_pcb]
2024-03-27 reworking the voltage regulator capacitors
    [mk19-rp2040.kicad_pcb, mk19-rp2040.kicad_sch]
2024-03-27 removing the other 10u caps and relocating the power in plug
    [mk19-rp2040.kicad_pcb, mk19-rp2040.kicad_sch]
2024-03-27 replaced the macro connector with a more solid-looking part, more rework
    [mk19-rp2040.kicad_pcb, mk19-rp2040.kicad_sch]
2024-03-28 updating silkscreens
    [mk19-rp2040.kicad_pcb]
2024-03-29 fixing silkscreen, changing out polyfuses to larger, improving trace routing
    [mk19-rp2040.kicad_pcb, mk19-rp2040.kicad_sch]
2024-03-29 adding the pull up-down for spi miso and sck, with solder jumpers
    [mk19-rp2040.kicad_pcb, mk19-rp2040.kicad_sch]
2024-04-03 moving things around for better physical fitment
    [mk19-rp2040.kicad_pcb, mk19-rp2040.kicad_sch]
2024-04-04 shipped to jlc
    [mk19-rp2040.kicad_pcb, mk19-rp2040.kicad_sch]
2024-04-27 fixing the manufacturing bugs - usb data crossed, flash pins 2 and 5 reversed, and v-cuts on wrong layer
    [mk19-rp2040.kicad_pcb, mk19-rp2040.kicad_sch]
2024-05-05 fixing layer on mounting hole footprint
    [mk19-rp2040.kicad_pcb]
2024-05-05 removing the serial power bypass
    [mk19-rp2040.kicad_pcb, mk19-rp2040.kicad_sch]
2024-05-05 moving reset
    [mk19-rp2040.kicad_pcb, mk19-rp2040.kicad_sch]
